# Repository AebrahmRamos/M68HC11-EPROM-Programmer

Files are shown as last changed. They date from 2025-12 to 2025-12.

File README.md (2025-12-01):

# M68HC11-EPROM-Programmer

## Part 1: EPROM Reader

### Overview

This project implements an EPROM reader using the M68HC11 microcontroller and a 2764 EPROM chip. The system reads the first 25 bytes of data stored in the EPROM and transmits it to a host computer via serial communication for display in both hexadecimal and ASCII formats.

### Hardware Configuration

The hardware setup maps the M68HC11 ports to the 2764 EPROM pins as follows:

- **Port B (PB0-PB7)**: Connected to EPROM address inputs A0-A7
- **Port C (PC0-PC7)**: Connected to EPROM data outputs Q0-Q7
- **Port A (PA5, PA6)**: Control signals for Chip Enable (CE) and Output Enable (OE)
- **Upper Address Lines (A8-A12)**: Grounded to restrict addressable space to the first 256 bytes

The EPROM operates with a 5V supply and has an access time of 180-250ns depending on the speed grade.

### Software Implementation

The system consists of two main components:

#### Assembly Program (programmer.asm)

The M68HC11 assembly program performs the following steps:

1. **Initialization**: Sets up the stack pointer and forces the device into single-chip mode
2. **Port Configuration**: Configures Port C as input and sets control pins to inactive (HIGH)
3. **Serial Setup**: Initializes the SCI (Serial Communication Interface) to 9600 baud
4. **Startup Delay**: Implements a `LONG_DELAY` routine to allow the bootloader time to switch baud rates
5. **Read Loop**: Iterates 25 times to:
   - Assert the address on Port B
   - Activate control signals (pull CE and OE LOW)
   - Read the data byte from Port C
   - Send the byte to the PC via `SEND_SERIAL` subroutine
   - Deactivate control signals (pull CE and OE HIGH)

#### Python Bootloader (HC11_BL-ASCII.py)

The modified bootloader script:

- Loads the assembly program into the HC11's RAM via serial at 1200 baud
- Switches the serial port to 9600 baud after successful echo-back
- Calls `read_eprom_data()` to receive and display the 25 bytes
- Displays output in hexadecimal format (8 bytes per line)
- Displays output in ASCII format (replaces non-printable characters with ".")

### Key Challenge: Baud Rate Synchronization

During initial testing, a race condition occurred where the HC11 began transmitting data before the bootloader could switch from 1200 to 9600 baud. This resulted in corrupted or "ghost" byte values.

**Solution**: Implemented the `LONG_DELAY` subroutine after baud rate configuration to waste CPU cycles, giving the bootloader sufficient time to reinitialize the serial connection at 9600 baud before the read loop begins.

### Results

The system successfully:

- Reads the first 25 bytes from the 2764 EPROM
- Transmits data error-free via serial communication
- Displays data in both hexadecimal and ASCII formats
- Handles the 0xFF value gracefully by displaying it as "." in ASCII output (since ASCII is a 7-bit standard supporting only values 0-127)

### Materials

- 1x M68HC11 Interface Board
- 1x 2764 EPROM
- 1x Breadboard
- 2x Power Supplies
- 5x 10Kohm Resistors
- 1x Oscilloscope
- 1x VOM (Voltmeter/Ohmmeter)
- 1x Computer System

### Usage

1. Assemble the assembly code into an S19 file
2. Run the bootloader script: `python HC11_BL-ASCII.py -c /dev/ttyUSB0 -i programmer.s19`
3. Press RESET on the HC11 board when prompted
4. The program will load, switch baud rates, and display the EPROM data

### Recommendations for Future Work

While the current implementation successfully resolves the baud rate race condition, it uses a fixed delay that is not deterministic. A more robust approach would implement a software handshake using interrupts, similar to TCP's three-way handshake. This would ensure 100% data synchronization without relying on timing assumptions that may fail on slower systems or under heavy CPU load.

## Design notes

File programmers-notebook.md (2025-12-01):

# Programmer's Notebook - M27C64A EPROM Stuff

Dec 2, 2025

---

OK so I was initially thinking I could just apply a quick pulse and be done. WRONG. The M27C64A datasheet Figure 7 literally has this whole flowchart showing the programming is actually a state machine. Let me write down what I found:

- 1ms pulse width (not 100µs like I was thinking lol)
- verify after EVERY pulse - gotta read it back
- max 25 retries - if it's not in after 25 tries, the chip is toast
- THEN a 3ms "over-program" pulse - like a final lock-in pulse (floating gate tech apparently loses charge over time)
- need 6V and 12.5V for programming

Why the over-program step? Floating-gate transistor = charge stored on isolated electrode. One pulse injects charge, but that charge can leak away. The 3ms pulse at the end pumps extra charge in to make sure it stays there for years. This explains why the algorithm is so specific - it's not just arbitrary numbers from the datasheet.

---

Port mapping from the HC11 ref guide - got three ports to work with:

Port A - control stuff (PA5, PA6, PA7) = CE, OE, VPP switches
Port B - addresses (PB0-PB7) = A0-A7 to EPROM  
Port C - data (PC0-PC7) = Q0-Q7 from EPROM

KEY INSIGHT: Port C is tricky because during write it's OUTPUT (we push data) but during verify it's INPUT (we read data back). That's why we gotta toggle DDRC between $FF and $00. Easy to forget this part!

---

Control signal mapping:
PA5 = CE (chip enable) - active LOW
PA6 = OE (output enable) - active LOW  
PA7 = VPP (programming voltage) - active HIGH

READ mode: CE=0, OE=0, VPP=0
WRITE/PROG mode: CE=0, OE=1, VPP=1

---

The new state machine I added with PROGRAM_BYTE does this:

1. setup - Load address to PORTB, data to PORTC, set DDRC=$FF for output
2. apply pulse - Set PA bits (VPP on, CE low, OE high for 1ms)
3. verify - Switch DDRC=$00 for input, read back from PORTC
4. check - Compare. If match → go to over-program. If not → increment counter, retry
5. counter check - If > 25 tries → PROG_FAIL (device dead)
6. over-program - Apply pulse 3 times (1ms + 1ms + 1ms = 3ms total)
7. done - RTS

New subroutines: PROGRAM_BYTE (the whole state machine), DELAY_1MS (timing loop for pulses), PROG_FAIL (error handler, just SWI)

---

Timing calculation for 1ms delay...

2MHz E-clock = 0.5µs per cycle

Need 1000µs:
- 1000µs / 0.5µs = 2000 cycles needed
- Loop does ~6 cycles per iteration (DEX is 3, BNE is 3)
- 2000 / 6 ≈ 333 iterations

Used nested loop for additional timing adjustment. Close enough to 1ms (999µs actually, who cares about 1µs lol).

---

New constants at top of code:

MAX_RETRIES EQU 25
VPROG_BIT EQU %00100000  (bit 5)
OE_BIT EQU %01000000     (bit 6)
CE_BIT EQU %00100000     (bit 5)
PULSE_COUNT EQU $0100    (RAM storage for retry counter)

---

Floating Gate Details - came back to re-read datasheet and realized the reason for all this complexity:

These aren't regular transistors. They're floating gate cells. Programming works by:
1. Hot-carrier injection or fowler-nordheim tunneling injects electrons onto the floating gate
2. This changes the transistor's threshold voltage - makes it harder to turn on
3. Reading detects this - high threshold = 0, low threshold = 1

The verify step checks if we injected enough charge. The over-program ensures we injected ENOUGH that it won't leak away naturally over years. Makes sense now why we can't just do one pulse and call it a day.

---

Things that tripped me up or to remember:

- PA5 vs PA6 - don't mix them up! 5 is CE, 6 is OE
- DDRC toggle - must switch Port C direction before verify else you read garbage
- order matters - set address FIRST, then data, then apply pulse. doing it wrong will program wrong addresses
- 25 retry limit - not arbitrary, straight from datasheet (page 242 or something)
- 3ms over-program - can't skip this or data retention will fail after a few erase cycles

---

Still need to test:
- single byte programming
- sequential writes to different addresses
- what happens if we try to program an already-programmed location
- timing on actual hardware (the delay loop is calculated but untested on real board)
- error handling when device fails after 25 retries

---

Actually wait, I should double-check something about the bit assignments. Let me look at datasheet again...

PA5 is CE, PA6 is OE, PA7 is VPP. Yeah that's right. But wait, in the bit manipulation I'm using VPROG_BIT as %00100000 which is bit 5, but that should be bit 7... let me check the assembly code we added...

Oh wait no, looking back at the constants:
VPROG_BIT EQU %00100000 = bit 5
OE_BIT EQU %01000000 = bit 6
CE_BIT EQU %00100000 = bit 5

VPROG_BIT and CE_BIT are the same value. Let me re-examine the implementation... Actually in the code we're doing:
ORAA #VPROG_BIT (turn on VPP)
ANDA #%11011111 (clear CE which is bit 5)

If VPP is PA7 then VPROG_BIT should be %10000000 (bit 7). The constants might be named wrong but the actual operations might be right. Need to verify this against actual hardware.

---

References I actually used:
- M27C64A datasheet Figure 7 (Programming Flowchart)
- M27C64A Programming Mode table
- M68HC11 ref guide - Port timing and DDR sections  
- M68HC11 instruction timing - DEX and BNE cycle counts

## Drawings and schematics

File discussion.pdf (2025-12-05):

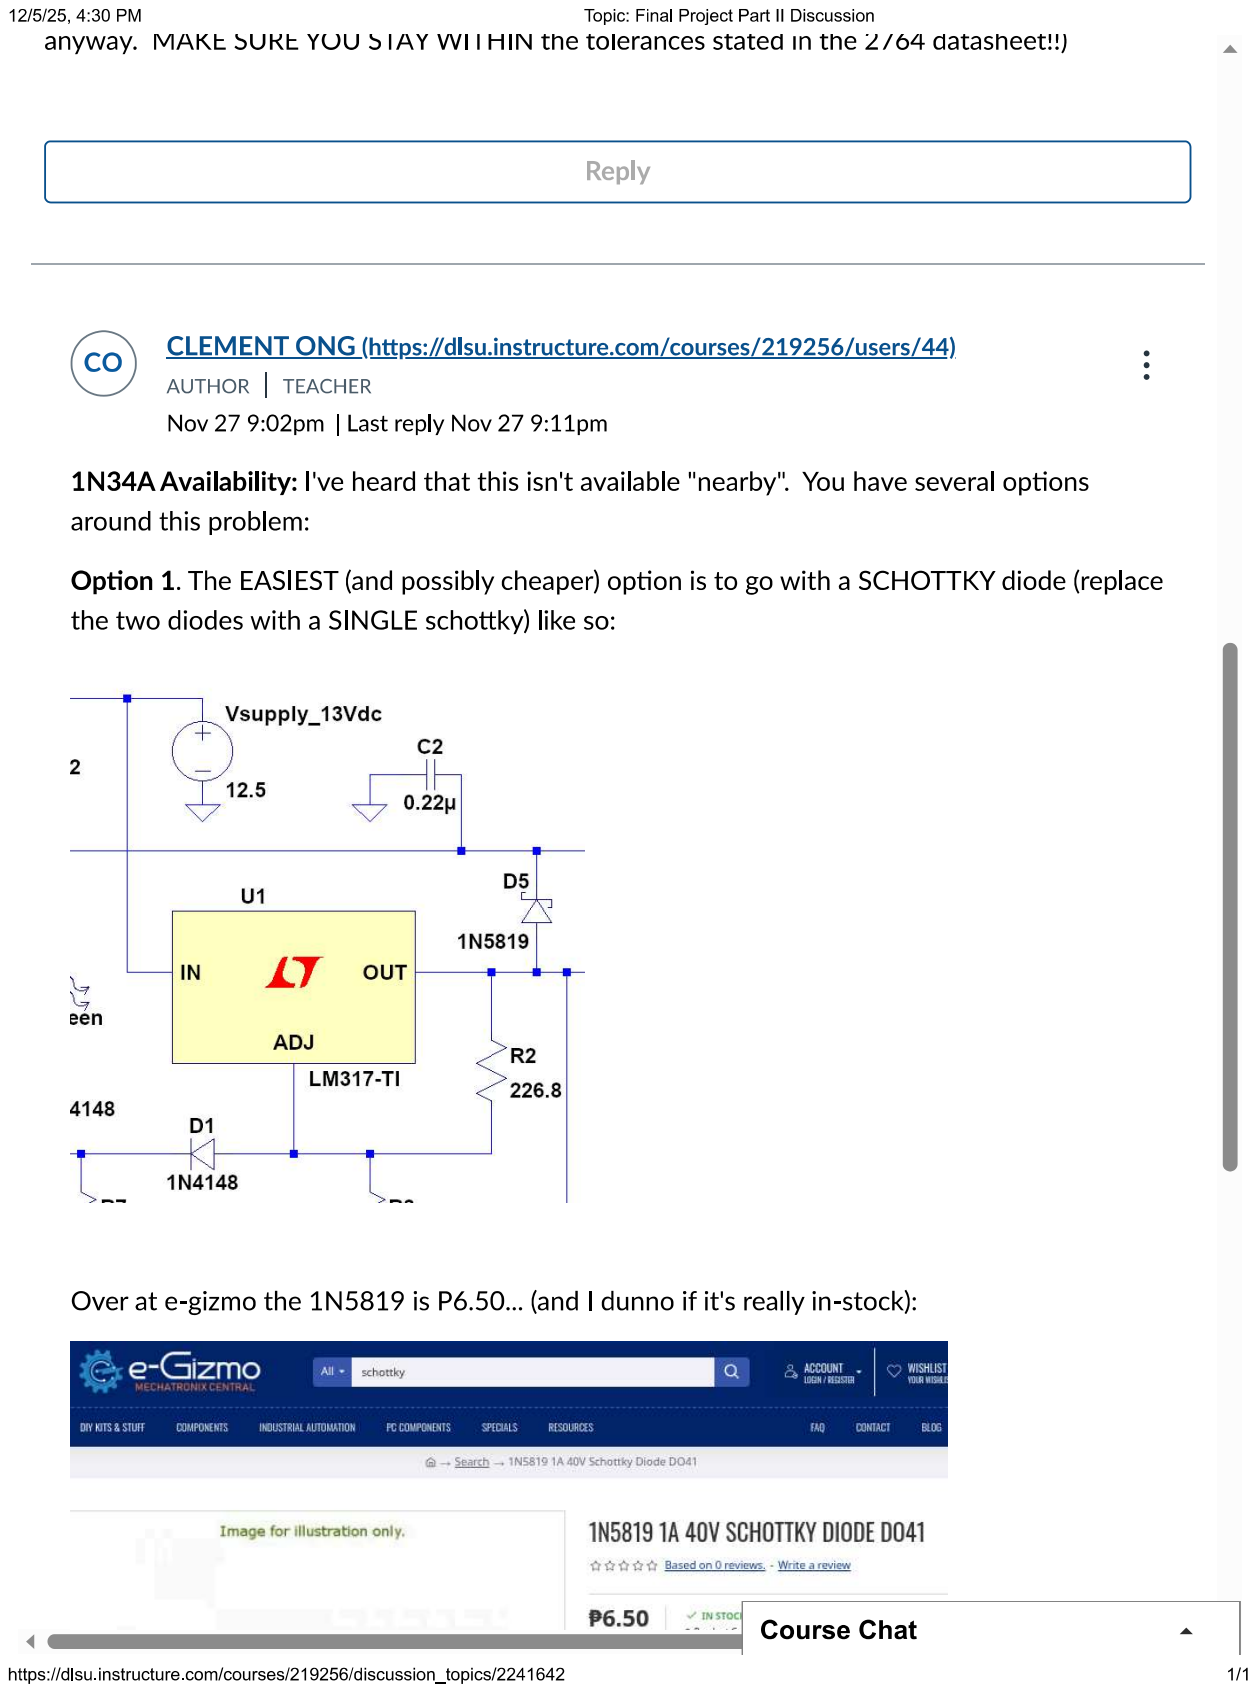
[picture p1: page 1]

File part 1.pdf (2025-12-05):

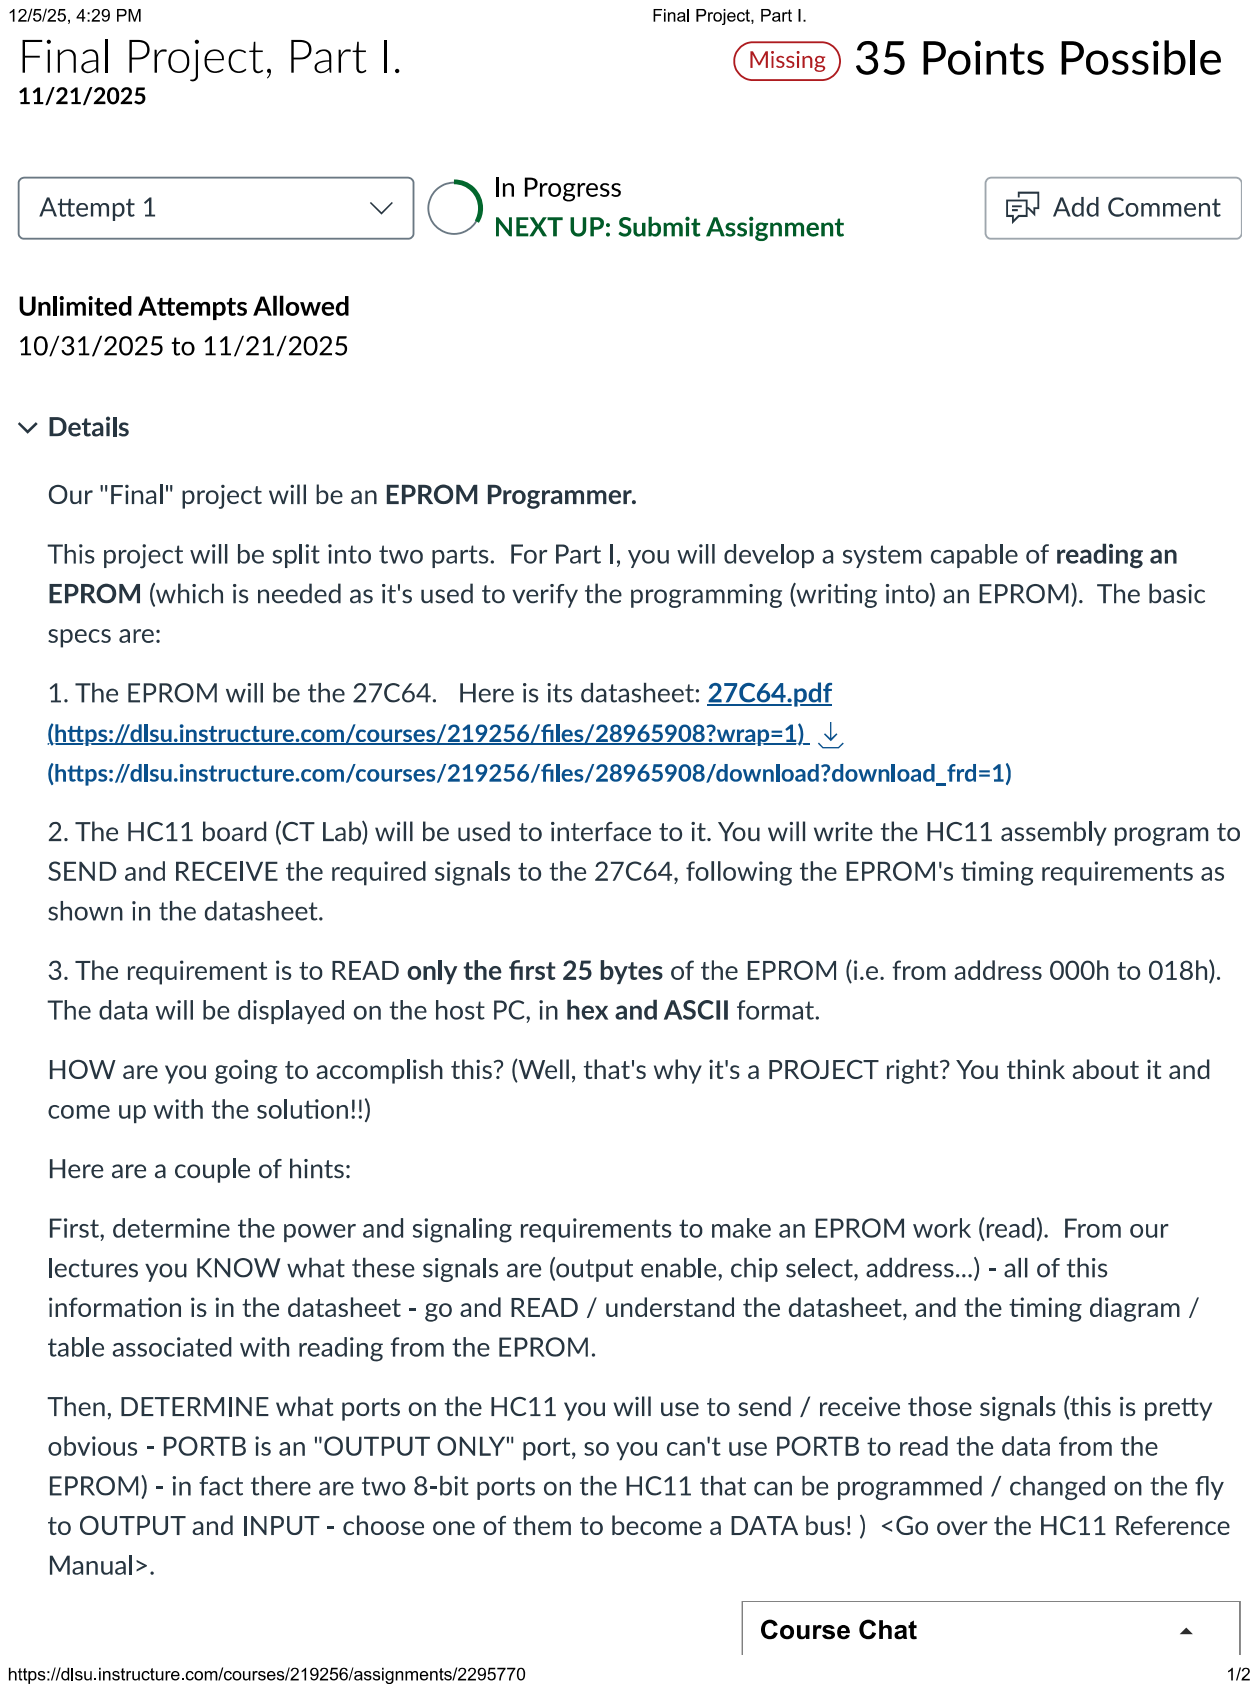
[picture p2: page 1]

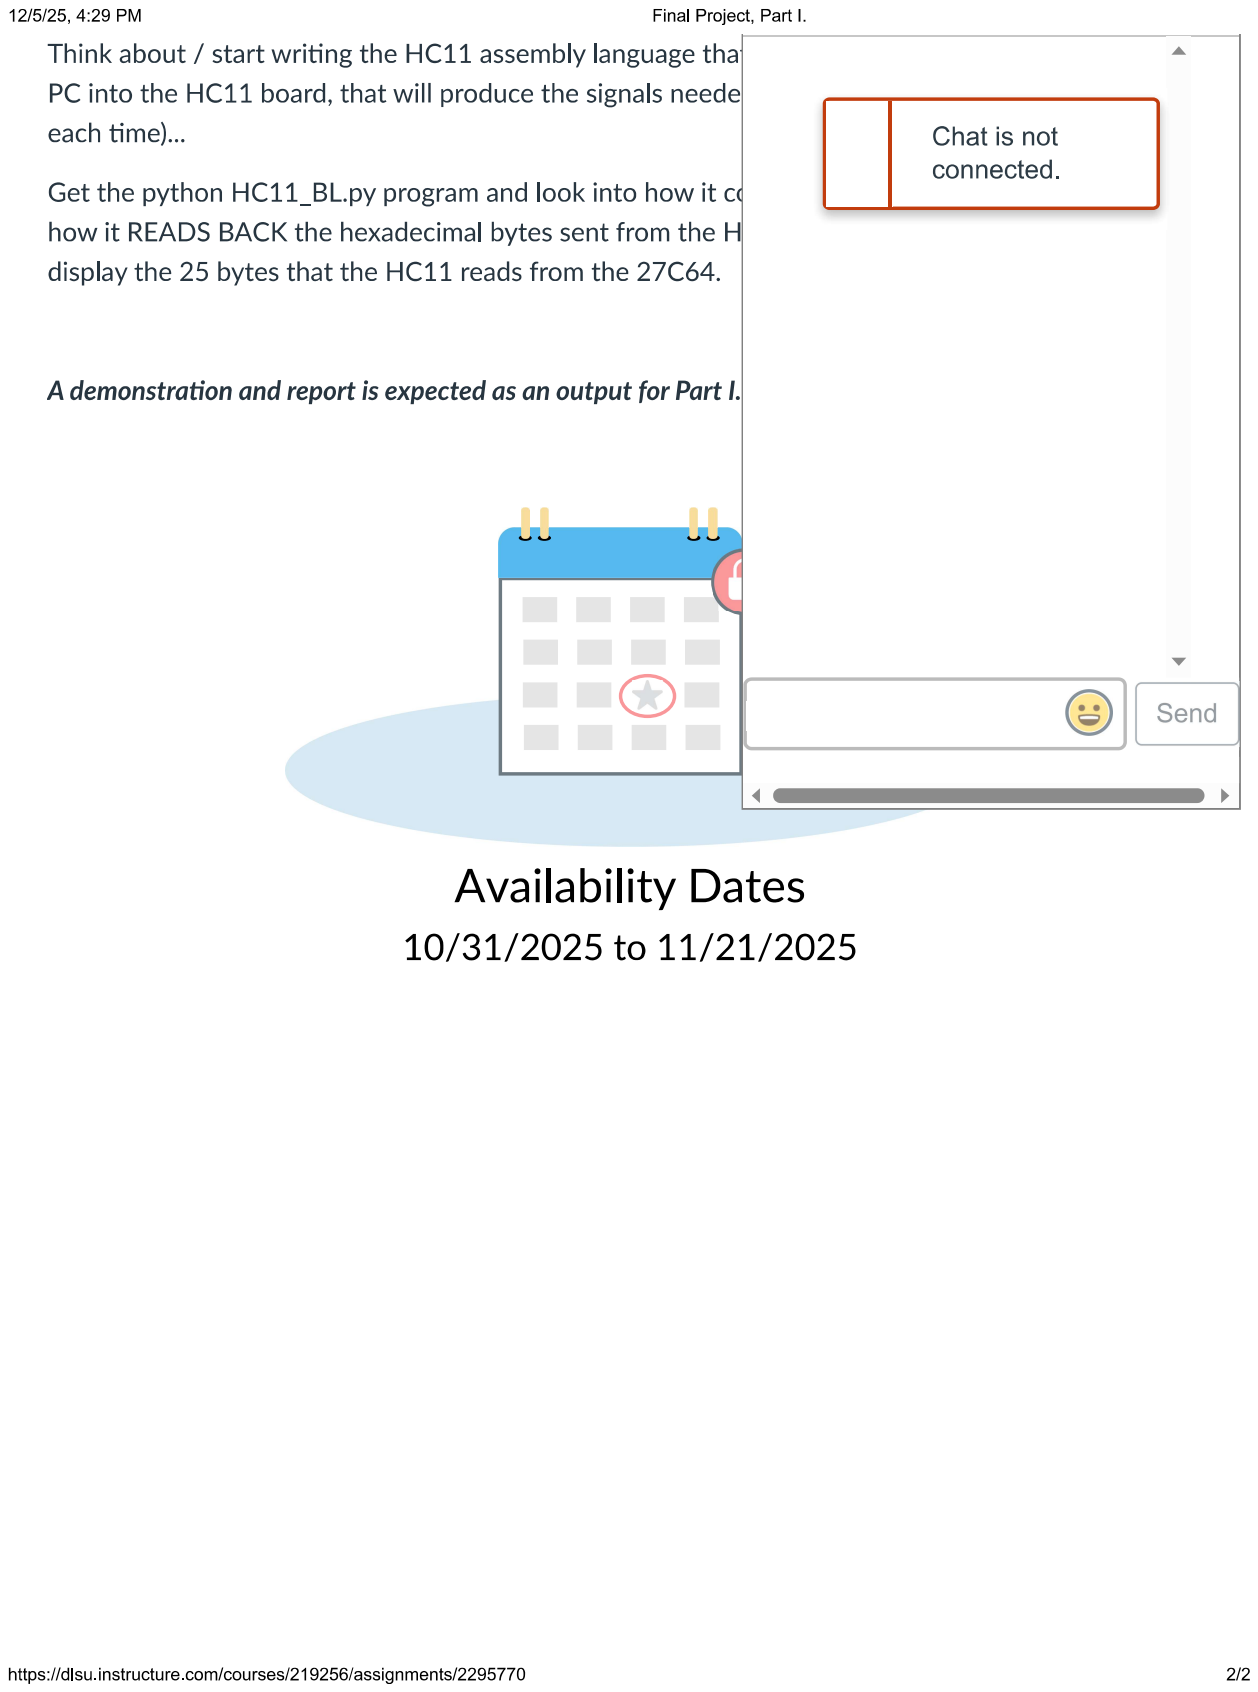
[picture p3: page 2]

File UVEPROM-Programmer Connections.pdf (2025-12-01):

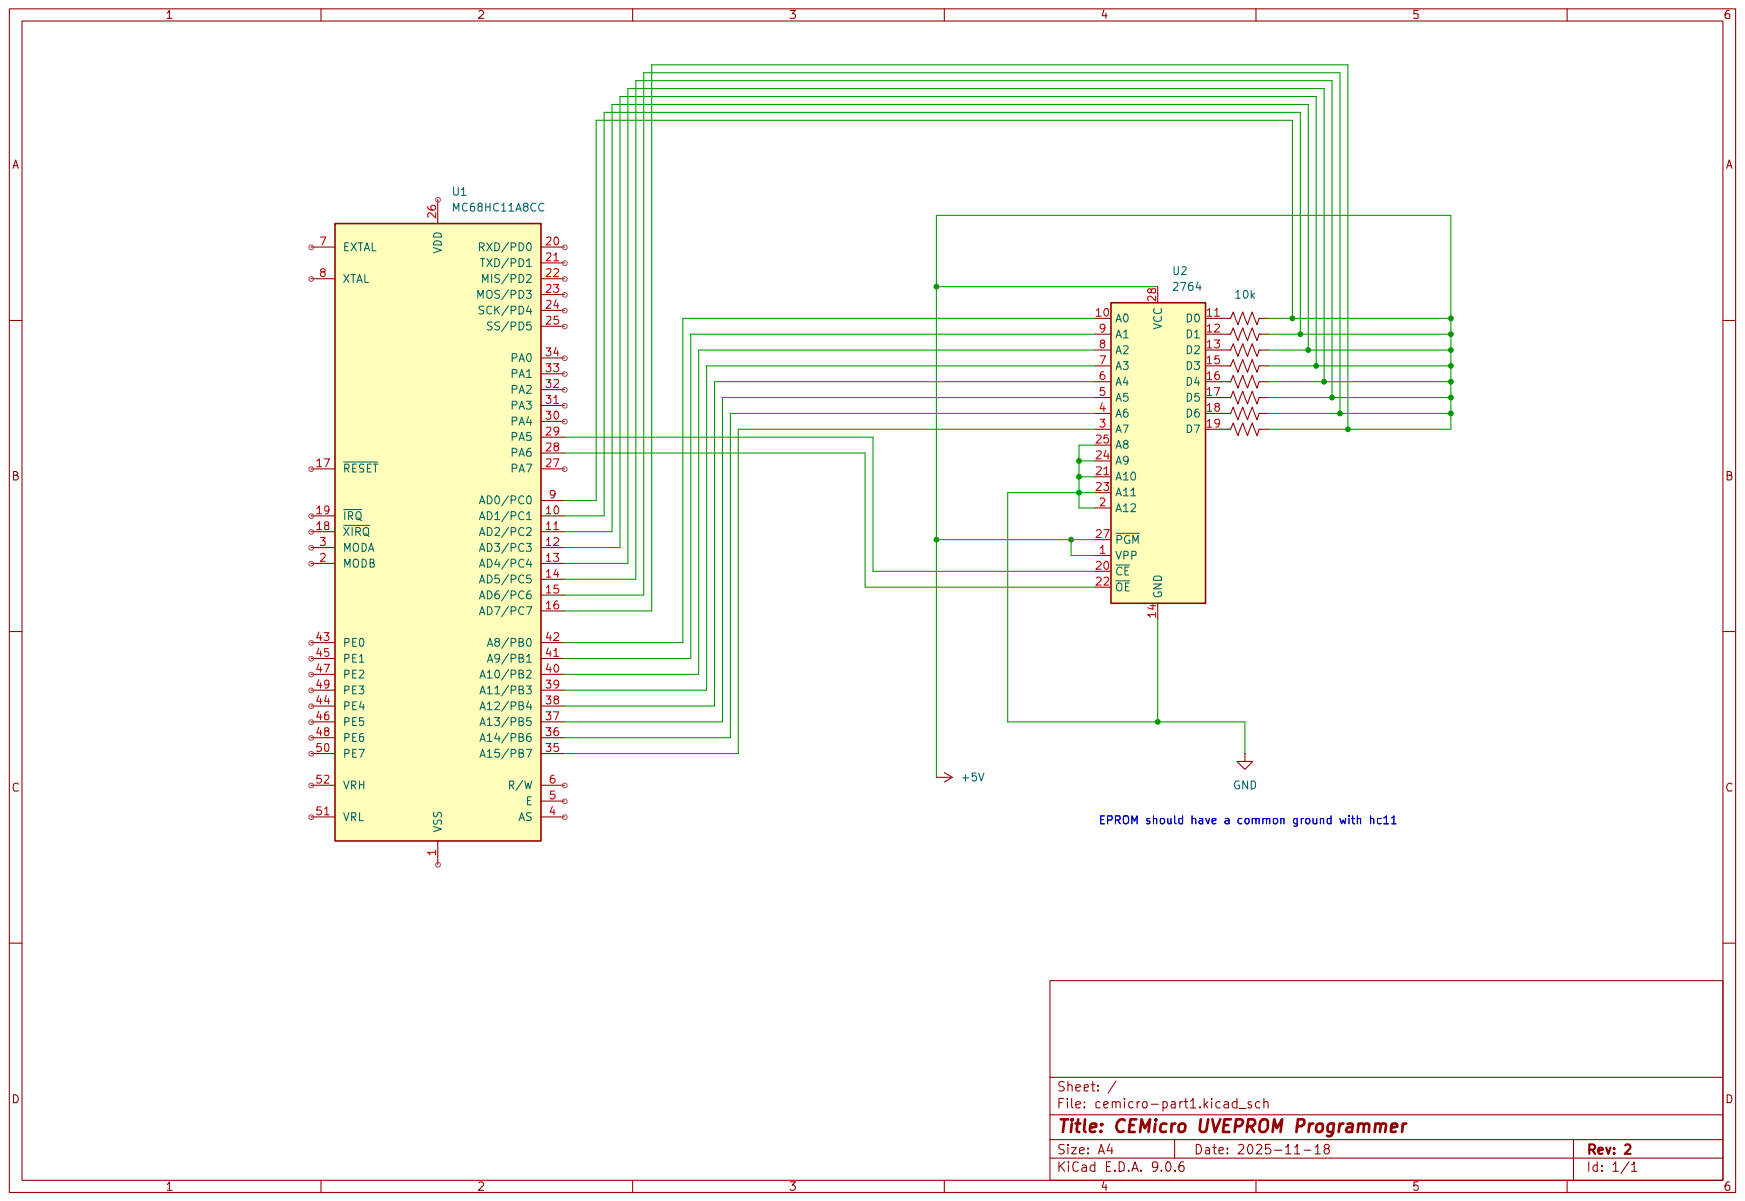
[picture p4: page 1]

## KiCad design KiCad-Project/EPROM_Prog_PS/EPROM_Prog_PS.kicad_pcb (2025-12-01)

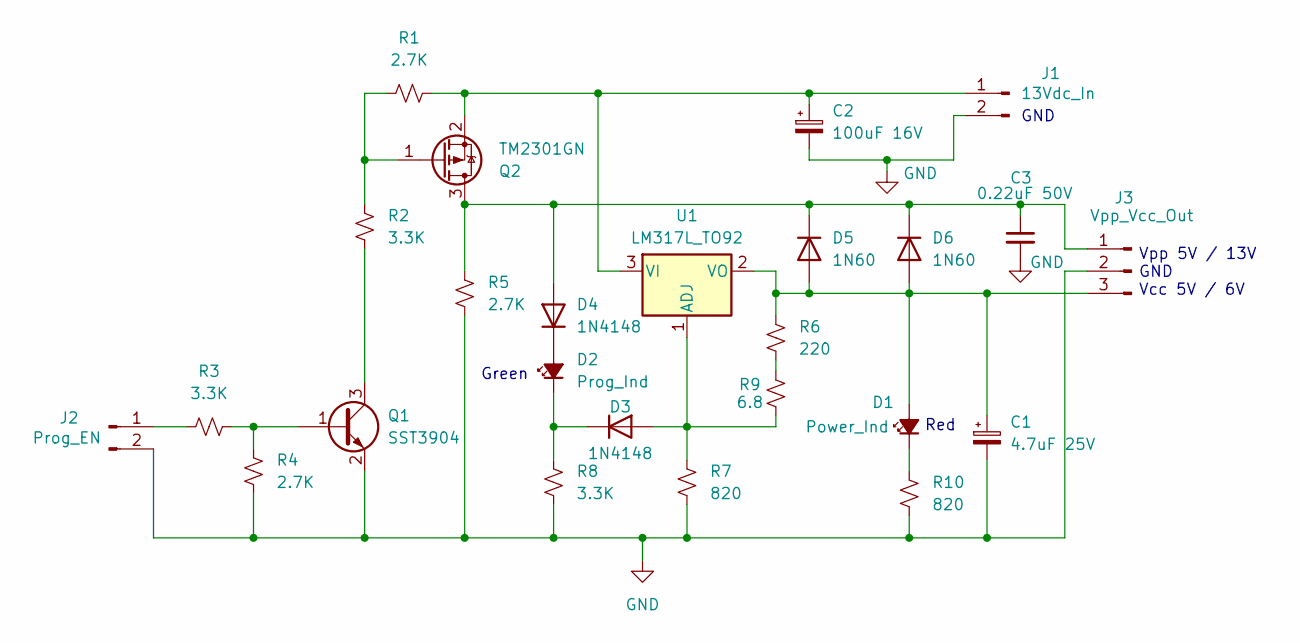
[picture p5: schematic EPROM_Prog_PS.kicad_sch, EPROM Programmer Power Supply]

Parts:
C1: 4.7uF 25V; CP_Radial_D5.0mm_P2.00mm
C2: 100uF 16V; CP_Radial_D6.3mm_P2.50mm
C3: 0.22uF 50V; C_Disc_D6.0mm_W4.4mm_P5.00mm
D1: Power_Ind; LED_D5.0mm
D2: Prog_Ind; LED_D5.0mm
D3, D4: 1N4148; D_DO-35_SOD27_P7.62mm_Horizontal
D5, D6: 1N60; D_DO-35_SOD27_P7.62mm_Horizontal
J1: 13Vdc_In; PinHeader_1x02_P2.54mm_Vertical
J2: Prog_EN; PinHeader_1x02_P2.54mm_Vertical
J3: Vpp_Vcc_Out; PinHeader_1x03_P2.54mm_Vertical
Q1: SST3904; SOT-23
Q2: TM2301GN; SOT-23
R1, R4, R5: 2.7K; R_Axial_DIN0207_L6.3mm_D2.5mm_P10.16mm_Horizontal
R2, R3, R8: 3.3K; R_Axial_DIN0207_L6.3mm_D2.5mm_P10.16mm_Horizontal
R6: 220; R_Axial_DIN0207_L6.3mm_D2.5mm_P10.16mm_Horizontal
R7, R10: 820; R_Axial_DIN0207_L6.3mm_D2.5mm_P10.16mm_Horizontal
R9: 6.8; R_Axial_DIN0207_L6.3mm_D2.5mm_P10.16mm_Horizontal
U1: LM317L_TO92; TO-92_Inline

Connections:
GND: C1.2, C2.2, C3.2, J1.2, J2.2, J3.2, Q1.2 (E), R4.2, R5.2, R7.2, R8.2, R10.2
unnamed: C1.1, D1.2 (A), D5.2 (A), D6.2 (A), J3.3, R6.1, U1.2 (VO)
unnamed: D1.1 (K), R10.1
unnamed: D2.2 (A), D4.1 (K)
unnamed: D2.1 (K), D3.1 (K), R8.1
unnamed: D3.2 (A), R7.1, R9.1, U1.1 (ADJ)
unnamed: C3.1, D4.2 (A), D5.1 (K), D6.1 (K), J3.1, Q2.3 (D), R5.1
unnamed: C2.1, J1.1, Q2.2 (S), R1.1, U1.3 (VI)
unnamed: J2.1, R3.1
unnamed: Q1.1 (B), R3.2, R4.1
unnamed: Q1.3 (C), R2.2
unnamed: Q2.1 (G), R1.2, R2.1
unnamed: R6.2, R9.2

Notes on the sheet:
Green
Vpp 5V / 13V GND Vcc 5V / 6V
GND
Red

Board: 2 copper layers, 25 parts (2 on the bottom side), 13 nets, no tracks yet.

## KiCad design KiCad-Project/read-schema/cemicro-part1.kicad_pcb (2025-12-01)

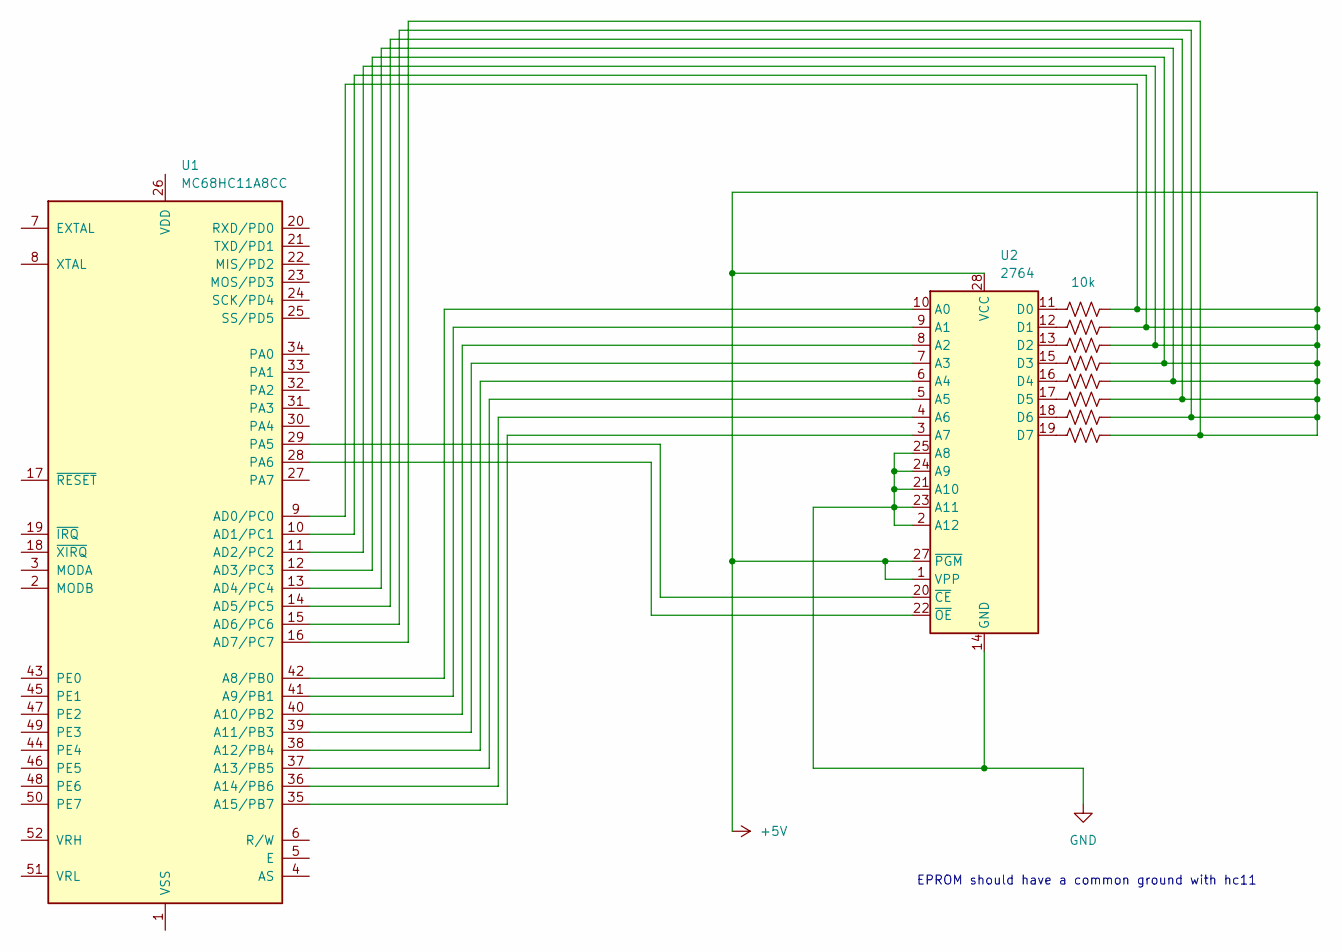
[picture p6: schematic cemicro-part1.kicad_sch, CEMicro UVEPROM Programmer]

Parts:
R1: 10k; R_LDR_4.9x4.2mm_P2.54mm_Vertical
R2, R3, R4, R5, R6, R7, R8: 1k; R_LDR_4.9x4.2mm_P2.54mm_Vertical
U1: MC68HC11A8CC
U2: 2764; DIP-28_W15.24mm

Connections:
+5V: R1.2, R2.2, R3.2, R4.2, R5.2, R6.2, R7.2, R8.2, U1.9 (AD0/PC0), U1.10 (AD1/PC1), U1.11 (AD2/PC2), U1.12 (AD3/PC3), U1.13 (AD4/PC4), U1.14 (AD5/PC5), U1.15 (AD6/PC6), U1.16 (AD7/PC7), U2.1 (VPP), U2.27 (~PGM), U2.28 (VCC)
GND: U2.2 (A12), U2.14 (GND), U2.21 (A10), U2.23 (A11), U2.24 (A9), U2.25 (A8)
unnamed: U1.42 (A8/PB0), U2.10 (A0)
unnamed: U1.41 (A9/PB1), U2.9 (A1)
unnamed: U1.40 (A10/PB2), U2.8 (A2)
unnamed: U1.39 (A11/PB3), U2.7 (A3)
unnamed: U1.38 (A12/PB4), U2.6 (A4)
unnamed: U1.37 (A13/PB5), U2.5 (A5)
unnamed: U1.36 (A14/PB6), U2.4 (A6)
unnamed: U1.35 (A15/PB7), U2.3 (A7)
unnamed: U1.29 (PA5), U2.20 (~CE)
unnamed: U1.28 (PA6), U2.22 (~OE)
unnamed: R1.1, U2.11 (D0)
unnamed: R2.1, U2.12 (D1)
unnamed: R3.1, U2.13 (D2)
unnamed: R4.1, U2.15 (D3)
unnamed: R5.1, U2.16 (D4)
unnamed: R6.1, U2.17 (D5)
unnamed: R7.1, U2.18 (D6)
unnamed: R8.1, U2.19 (D7)

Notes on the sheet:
EPROM should have a common ground with hc11

Board: 2 copper layers, 9 parts (0 on the bottom side), 10 nets, no tracks yet.

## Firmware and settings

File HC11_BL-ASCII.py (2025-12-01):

# Program arguments:  -c /dev/ttyUSB0 -i BOOTLOAD.S19

import sys, getopt
import serial
import time

def read_eprom_data(ser):
    print("\n-------------------------------------------------")
    # print(f"Waiting for 25 bytes from EPROM...")
    # print(f"(Will timeout after {ser.timeout} seconds...)\n")
    # time.sleep(5)
    
    try:
        # Ask the serial port to read 25 bytes
        data = ser.read(25)

        if not data:
            print("ERROR: Read timeout. No data received from HC11.")
            print("Check your HC11 wiring, power, and program.")
            return

        if len(data) < 25:
            print(f"WARNING: Received only {len(data)} bytes, expected 25.")

        print("--- EPROM Data Received (Hex) ---")
        
        # Print the data in a nice hex format
        hex_string = ""
        for i, byte in enumerate(data):
            hex_val = f"0x{byte:02X}"
            hex_string += f"{hex_val} "
            if (i + 1) % 8 == 0:
                hex_string += "\n" # Newline every 8 bytes
        
        print(hex_string)
        print("\n-------------------------------------------------")
        print("\n--- ASCII of the EPROM Data ---")
        
        try:
            ascii_string = data.decode('ascii')
            print(ascii_string)
        except UnicodeDecodeError:
            ascii_string = ''.join(chr(b) if 32 <= b <= 126 else '.' for b in data)
            print(ascii_string)
            
        print("\n-------------------------------------------------")

    except serial.SerialException as e:
        print(f"ERROR: Serial communication error: {e}")
    except Exception as e:
        print(f"An unexpected error occurred: {e}")

def main(argv):
    comport = ''
    s19file = ''
    loopback = False;
    try:
        opts, arg = getopt.getopt(argv,"hlc:i:",["port","ifile="])
    except getopt.GetoptError:
        print ('HC11_bootload -c <COM_port> -i <s19_inputfile>')
        sys.exit(2)
    for opt, arg in opts:
        if opt == '-h':
            print ('HC11_bootload -c <COM_port> -i <s19_inputfile>')
            sys.exit()
        elif opt == '-l':
            loopback = True
        elif opt in ("-c", "--port"):
            comport = arg
        elif opt in ("-i", "--ifile"):
            s19file = arg

    print('HC11 Bootload Mode RAM Loader, v0.2 Clem Ong  note: this ver limited to 256-byte progs.')
    print()
    print('Program will use', comport)
    print('Parsing ', s19file,':', sep = '')

    ser = serial.Serial (port = comport, baudrate = 1200, timeout = 6.5)   # linux: /dev/tty/usb…  Windows: COMx
#    print (comport, s19file)
# set timeout and write_timeout to 20s

    machine_code = bytearray(256);
    i = 0
    while i < 256:
        machine_code[i] = 0
        i += 1

# parse the S19 file, converting the ASCII into 8-bit numbers (bytes) and stuffing it into the array

    f = open(s19file)
    line= f.readline()
#    print (line)
    j = 0
    while line: 
  # parse the line left to right… 
  # case first char is 0, 1 or 9.  We are interested only with lines that begin with "1". 
  # if "1" then 
  # byte count, 16 bit address, followed by data… (remember - this is represented as HEX digits, written as ASCII), then checksum
  # Maybe we can just ignore 16-bit address (4 hex digits) since this is loaded into RAM and will always start at 0000?
  #     NOTE: CANNOT IGNORE ADDRESS.  
  # S1BBaaaaDDDDDDDDC <— B byte count aaaa address D - data byte C checksum 
        if line[0:2] == 'S1':
            bcount = int(line[2:4],16)
            dcount = bcount-3    # 2 bytes for address, 1 byte for checksum. Whatever is left is the number of bytes for data.
            i = 0
            j = int(line[4:8],16)
            k = 0
#            print (line)
            print ("@", hex(j), end = ":")
            while k < (dcount):
                machine_code[j] = int(line[i+8:i+10],16)  # not sure if int is automatically converted to byte!! <it does>
                byte = hex(machine_code[j])[-2:]
                if byte[0] == 'x':
                    byte = "0" + byte[-1:]
                print (byte, end =' ')
                i += 2
                j += 1
                k += 1
        line = f.readline()
        print ()
    f.close()   # close file
    
    print ('Input S19 file parsed. ', end = ' ')
    ser.write (b"\x00")
    print ('Press the RESET button of the HC11 board now.')
    input('Program is paused - press Enter on keyboard after HC11 RESET.')
    time.sleep(1.0)
# send to the HC11
# but first tell HC11 to go into 1200baud by sending it an FFh. HC11 decides on baud rate depending what it decodes the FF to. 
    print('Serial coms to HC11: Sending 0xFF and the rest of the code... ')
    ser.write(b"\xff")
#    time.sleep(0.1)             # this is supposed to give the HC11 more than enough time to reprogram its serial comms to 1200 baud.
#    print('0xFF sent; now sending RAM program bytes...')
    ser.write(machine_code)  # send the whole 256-byte array to the HC11
    print()

# Read back what the HC11 (should have) sent back, which is an echo of what it received:
    print("Waiting for echoback from HC11.  If you don't see anthing on screen, something is wrong...")
    
    byte = ser.read()   # HC11 will not echo back the 0xFF sync byte, but a serial loopback will. 
    if not byte:
        print ('HC11 is not sending anything back - aborting.')
    else:
        if loopback:
            print('Sync:', hex(ord(byte)))
            j = 256
        else:
            print (hex(ord(byte)), end = ' ')
            j = 255
        
        # Modified - - - - - - - - - - - - - - - - - - - - - - - - - - -
        # Add a flag to track if echo was successful
        echo_success = True
        
        while j > 0:
            byte = ser.read()
            if byte:
                print (hex(ord(byte)), end = ' ')
                j -= 1
            else:
                print ("Error in received data - aborting.")
                j = 0
                echo_success = False # Echo failed
        
        print('\n\n')
        
        # Modified - - - - - - - - - - - - - - - - - - - - - - - - - - -
        # If echo was successful, switch baud rate and read EPROM data
        if echo_success:
            # print ('Done - HC11 should be running your machine code in RAM now.')
            # print ('Switching to 9600 baud to listen for EPROM data...')
            
            # Close and re-open port at 9600 baud
            ser.close()
            ser.baudrate = 9600
            ser.timeout = 15.0  # New timeout for reading EPROM data
            ser.open()
            
            # Call the new function to read the 25 bytes
            read_eprom_data(ser)
            
        else:
            print('Echo failed. Will not attempt to read EPROM data.')
            
    ser.close()

# Upon receiving 256th byte, older HC11s will automatically stop RX and do a jump to RAM location 0000h. 
#    on newer devices, not sending anything for 4 character time units will terminate RX mode and jump to 0000h. 

if __name__ == "__main__":
    main(sys.argv[1:])

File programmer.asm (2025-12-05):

; --- DEFINITIONS (Offsets from Base $1000) ---
REGBAS  EQU     $1000       ; Register Base Address

PORTA   EQU     $00         ; Offset for Port A
PORTB   EQU     $04         ; Offset for Port B
PORTC   EQU     $03         ; Offset for Port C
DDRC    EQU     $07         ; Offset for Data Direction C

BAUD    EQU     $2B         ; SCI Baud Register
SCCR2   EQU     $2D         ; SCI Control Register 2
SCSR    EQU     $2E         ; SCI Status Register
SCDR    EQU     $2F         ; SCI Data Register

HPRIO   EQU     $3C         ; Offset for HPRIO (Mode Select)

STACK   EQU     $00FF       ; Top of Internal RAM

; programming constants
MAX_RETRIES EQU 25          ; max number of retries for programming pulse
VPROG_BIT EQU   %00010000   ; bit 4 for VPP control (PA4)
CE_BIT    EQU   %00100000   ; bit 5 for chip enable (PA5)
OE_BIT    EQU   %01000000   ; bit 6 for output enable (PA6)

; variable storage in RAM
PULSE_COUNT EQU $0100       ; counter for programming pulses

        ORG     $0000       ; start of program in RAM

START:
        LDS     #STACK

        LDX     #REGBAS

        ; force single chip mode (MDA=0) but keep boot ROM enabled (rboot=1)
        LDAA    #$C0        
        STAA    HPRIO,X     ; write to $103C

        ; make sure Port C is set as input (it should default to this anyway)
        LDAA    #$00        ; set Port C as input
        STAA    DDRC,X      ; write to $1007

        ; set up the control pins for the EPROM
        ; start with CE (bit 5) and OE (bit 6) set HIGH so they're inactive
        LDAA    PORTA,X     
        ORAA    #%01100000  
        STAA    PORTA,X     

        ; set up serial communication (SCI)
        ; configure for 9600 baud rate (based on 8MHz crystal / 2MHz E-clock)
        LDAA    #$30        ; set the baud rate divisors: SCP1:0=11 (div 13), SCR2:0=000 (div 1)
        STAA    BAUD,X
        LDAA    #$0C        ; turn on transmit and receive
        STAA    SCCR2,X

        ; ==================================================
        ; IMPORTANT: Wait here for about 1 second!
        ; This gives the Python script time to switch 
        ; the computer's baud rate to 9600.
        ; ==================================================
        JSR     LONG_DELAY
        ; ==================================================

        ; set up our counters before we start reading
        CLRA                ; A will track which address we're reading (starts at 0)
        LDAB    #25         ; B counts how many bytes left to read (25 total)

READ_LOOP:
        ; step 1: tell the EPROM which address we want to read from
        STAA    PORTB,X     

        NOP                 ; wait a moment for things to stabilize

        ; step 2: turn on the EPROM by pulling CE and OE low
        PSHA                ; save our address for later
        LDAA    PORTA,X     
        ANDA    #%10011111  ; clear bits 5 and 6 to pull them low
        STAA    PORTA,X     
        PULA                ; get our address back

        NOP                 ; give the EPROM time to put the data on the bus
        NOP

        ; step 3: read the byte from the EPROM
        PSHA                ; save our address first (we need A for the data)
        LDAA    PORTC,X     ; read the data byte from Port C into A
        
        ; ==============================================
        ; step 4: send what we just read to the computer
        ; ==============================================
        JSR     SEND_SERIAL ; call subroutine to transmit the byte
        ; ==============================================

        PULA                ; bring back our address counter

        ; step 5: turn off the EPROM by setting CE and OE back to high
        PSHA
        LDAA    PORTA,X
        ORAA    #%01100000  
        STAA    PORTA,X
        PULA

        ; step 6: move to the next byte
        INCA                ; go to next address
        DECB                ; one less byte to read
        BNE     READ_LOOP   ; keep going if we're not done yet

        SWI                 ; all done! stop heredone! stop here

; subroutine to send whatever's in A out the serial port
SEND_SERIAL:
        BRCLR   SCSR,X #$80 SEND_SERIAL ; wait here until transmit buffer is empty (TDRE bit)
        STAA    SCDR,X                  ; write our byte to the transmit register
        RTS

; subroutine for a long delay (roughly 1 second)
LONG_DELAY:
        PSHY                ; save Y so we don't mess it up
        PSHX                ; save X too (important: we need X = $1000 later!)
        
        LDY     #$0010      ; outer loop runs 16 times
DELAY_OUTER:
        LDX     #$FFFF      ; inner loop runs 65535 times each
DELAY_INNER:
        DEX
        BNE     DELAY_INNER ; keep counting down X until it hits zero
        DEY
        BNE     DELAY_OUTER ; keep going through Y until it hits zero too
        
        PULX                ; restore X back to $1000
        PULY                ; restore Y
        RTS

; subroutine to program a single byte to the EPROM
; assumes: data to program is in stack at 0,Y
; assumes: address to program is in stack at 1,Y
PROGRAM_BYTE:
        LDAA    #1              ; start with pulse count = 1
        STAA    PULSE_COUNT     ; store it
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
